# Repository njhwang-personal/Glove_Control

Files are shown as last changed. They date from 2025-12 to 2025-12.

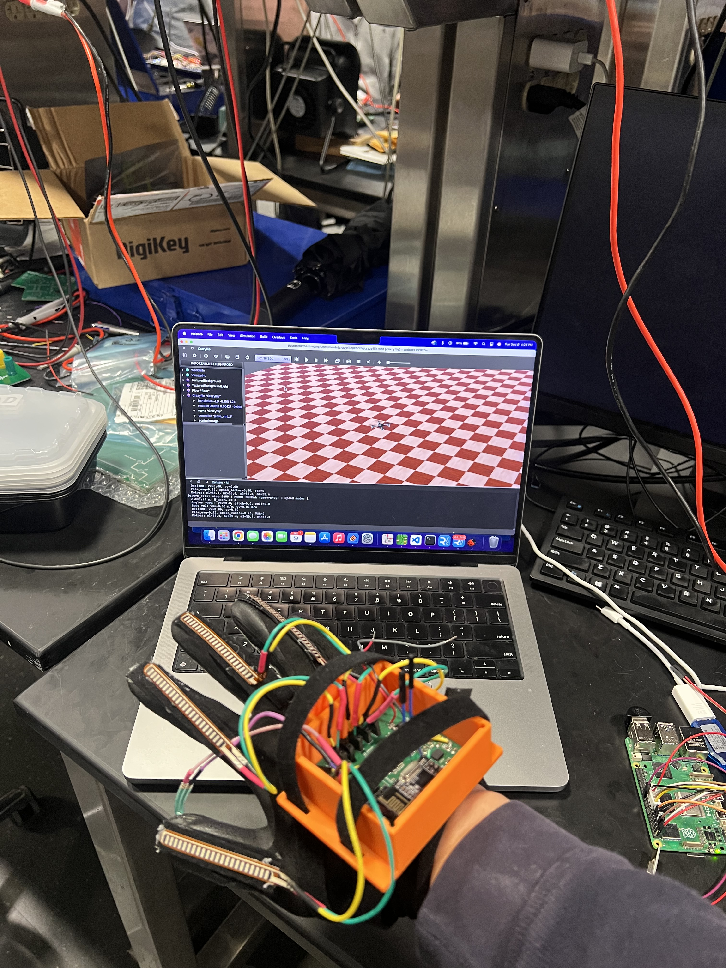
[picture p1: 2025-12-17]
IMG_4266.jpeg

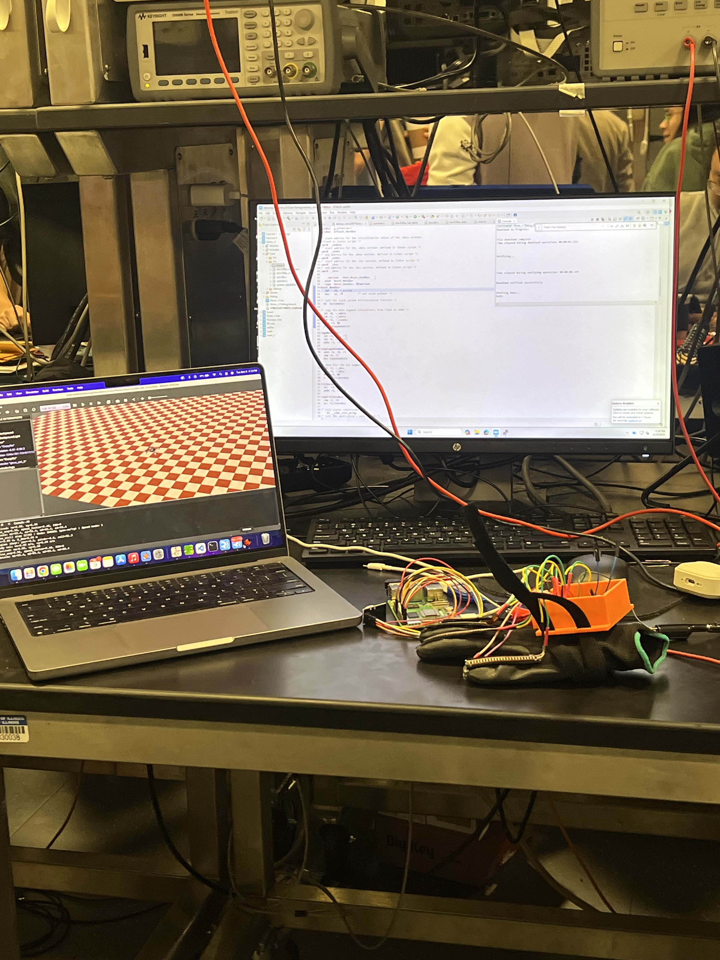
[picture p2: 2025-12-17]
IMG_4262.jpeg

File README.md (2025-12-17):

# Glove-Controlled Drone

## Overview
This project implements a wearable glove controller for drone control using a custom PCB, wireless communication, and a simulated drone environment.

## Repository Contents
- `glove_ctrl.py` – Webots controller code
- `glove_main.c` – STM32 firmware (STM32CubeIDE)
- `pi_receiver_final.c` – Raspberry Pi RF receiver and UDP bridge
- `Glove_32pin.kicad*` – KiCad schematic and PCB layout files for the glove controller

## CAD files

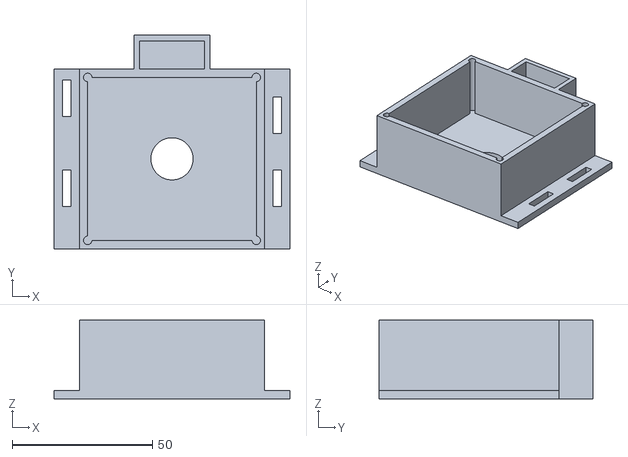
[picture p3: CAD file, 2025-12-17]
Gloves_case_final.stl
84.0 x 76.0 x 28.0

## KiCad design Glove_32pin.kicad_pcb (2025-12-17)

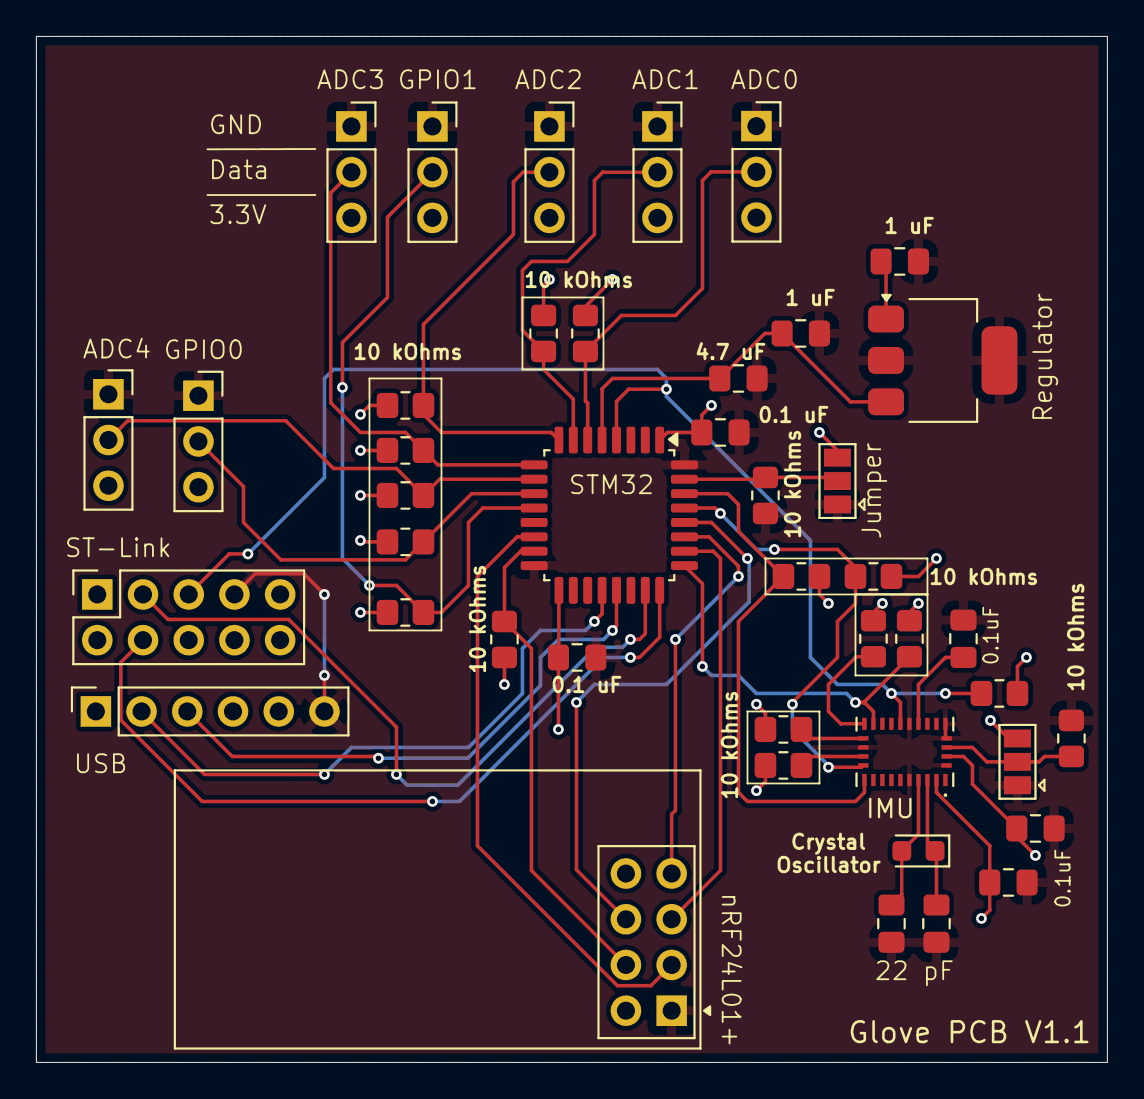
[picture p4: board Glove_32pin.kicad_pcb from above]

Board: 2 copper layers, 59.5 x 57.0 mm, 43 parts (0 on the bottom side), 32 nets.

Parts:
C1, C2: 1 uF; C_0805_2012Metric_Pad1.18x1.45mm_HandSolder
C3, C4, C6, C7, C10: 0.1 uF; C_0805_2012Metric_Pad1.18x1.45mm_HandSolder
C5: 4.7 uF; C_0805_2012Metric_Pad1.18x1.45mm_HandSolder
C8, C9: 22 pF; C_0805_2012Metric_Pad1.18x1.45mm_HandSolder
J3, J4, J5, J6, J7, J8, J9: Conn_01x03_Pin; PinSocket_1x03_P2.54mm_Vertical
J10: ST-Link; PinSocket_2x05_P2.54mm_Vertical
J12: Conn_01x06_Socket; PinSocket_1x06_P2.54mm_Vertical
JP1, JP4: SolderJumper_3_Open; SolderJumper-3_P1.3mm_Open_Pad1.0x1.5mm
R1, R13: 10KOhms; R_0805_2012Metric_Pad1.20x1.40mm_HandSolder
R2, R3, R4, R12: 4.7 kOhms; R_0805_2012Metric_Pad1.20x1.40mm_HandSolder
R5, R6, R7, R8, R9, R10, R11: 22 kOhms; R_0805_2012Metric_Pad1.20x1.40mm_HandSolder
R14, R15, R16, R19: 10K; R_0805_2012Metric_Pad1.20x1.40mm_HandSolder
U1: STM32L031K6Tx; LQFP-32_7x7mm_P0.8mm
U2: TC1262-33; SOT-223-3_TabPin2
U3: BNO085; IC_BNO085
U5: NRF24L01_Breakout; nRF24L01_Breakout
X1: 32.768; Crystal_SMD_2012-2Pin_2.0x1.2mm_HandSoldering

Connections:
+3.3V: C3.2, C4.1, C7.1, C10.1, J3.3, J4.3, J5.3, J6.3, J7.3, J8.3, J9.3, J10.1, J10.6, JP1.3 (B), JP4.3 (B), R2.2, R3.2, R4.2, R5.1, R6.1, R7.1, R8.1, R9.1, R10.1, R11.1, R12.2, R14.2, R15.2, R16.1, R19.1, U1.1 (VDD), U1.17 (VDD), U3.3 (VDD), U3.28 (VDDIO), U5.2 (VCC)
+5V: C2.1, U2.1 (VI)
/ADC0: J3.2, R5.2, U1.6 (PA0)
/ADC1: J4.2, R6.2, U1.7 (PA1)
/ADC2: J5.2, R7.2, U1.8 (PA2)
/ADC3: J6.2, R8.2, U1.9 (PA3)
/ADC4: J7.2, R9.2, U1.10 (PA4)
/GPIO_0: J8.2, R10.2, U1.11 (PA5)
/GPIO_1: J9.2, R11.2, U1.12 (PA6)
/I2C_SCL: R3.1, U1.29 (PB6), U3.19 (H_SCL/SCK/RX)
/I2C_SDA: R2.1, U1.30 (PB7), U3.20 (H_SDA/H_MISO/TX)
/INT: R12.1, U1.25 (PA15), U3.14 (~H_INT)
/LPUART_Rx: J12.3, U1.21 (PA11)
/LPUART_Tx: J12.2, U1.20 (PA10)
/NRST: J10.5, R19.2, U1.4 (NRST), U3.11 (~RST)
/SPI_CE: U1.14 (PB0), U5.3 (CE)
/SPI_CSN: R4.1, U1.15 (PB1), U5.4 (~CSN)
/SPI_MISO: U1.27 (PB4), U5.7 (MISO)
/SPI_MOSI: U1.28 (PB5), U5.6 (MOSI)
/SPI_SCK: U1.26 (PB3), U5.5 (SCK)
/SWCLK: J10.4, U1.24 (PA14)
/SWDIO: J10.3, U1.23 (PA13)
/XIN: C8.1, U3.27 (XIN32), X1.1
/XOUT: C9.1, U3.26 (XOUT32/CLKSEL1), X1.2
GND: C1.2, C2.2, C3.1, C4.2, C5.2, C6.2, C7.2, C8.2, C9.2, C10.2, J3.1, J4.1, J5.1, J6.1, J7.1, J8.1, J9.1, J10.7, J12.6, JP1.1 (A), JP4.1 (A), R1.2, R13.2, U1.16 (VSS), U1.32 (VSS), U2.2 (GND), U3.2 (GND), U3.5 (PS1), U3.6 (PS0/WAKE), U3.10 (CLKSEL0), U3.17 (SA0/H_MOSI), U3.25 (GNDIO), U5.1 (GND)
unnamed: JP1.2 (C), R1.1, U1.31 (BOOT0)
unnamed: JP4.2 (C), R13.1, U3.4 (~BOOT)
unnamed: C1.1, C5.1, U1.5 (VDDA), U2.3 (VO)
unnamed: C6.1, U3.9 (CAP)
unnamed: R14.1, U3.15 (ENV_SCL)
unnamed: R15.1, U3.16 (ENV_SDA)
unnamed: R16.2, U3.18 (~H_CS)

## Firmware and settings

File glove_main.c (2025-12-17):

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
/* Includes ------------------------------------------------------------------*/
#include "main.h"

#include <stdio.h>
#include <stdlib.h>
#include <string.h>
#include <math.h>
#include <stdint.h>
#include <stdbool.h>

/* USER CODE END Includes */


/* USER CODE BEGIN PTD */

////// Define for Bno085 //////
#define RAD_TO_DEG (57.2957795131f)
#define SCALE_Q14 (1.0f/16384.0f)
#define BNO_I2C_ADDRESS (0x4A << 1)
#define BNO_I2C_HANDLE &hi2c1
#define BNO_MSG_LENGTH 21
#define BNO_READ_PERIOD 20 //ms


ADC_HandleTypeDef hadc;
I2C_HandleTypeDef hi2c1;
UART_HandleTypeDef huart4;
SPI_HandleTypeDef hspi1;


uint8_t START_BNO_STABILIZED_ROTATION_VECTOR_100_HZ[/* BNO_MSG_LENGTH */] =
{ 0x15, 0x00, 0x02, 0x00, 0xFD, 0x28, 0x00, 0x00, 0x00, 0x10, 0x27, 0x00, 0x00,
	0x00, 0x00, 0x00, 0x00, 0x00, 0x00, 0x00, 0x00 };

uint8_t FishedOutMessage[BNO_MSG_LENGTH];
uint8_t BnoRxBuff[BNO_MSG_LENGTH];
static int16_t Data1, Data2, Data3, Data4;



typedef struct __attribute__((packed)){
    uint8_t  magic;      //0xAA
    uint8_t  version;
    uint16_t seq;

    int16_t  yaw;
    int16_t  pitch;
    int16_t  roll;

    uint8_t  flex[5];
    uint8_t  contacts;

    uint16_t batt_mv;    //battery (unused)

    uint8_t  reserved[12];  //future use

    uint16_t checksum;   //16-bit sum of first 30 bytes
} GlovePacket;

static uint16_t g_seq = 0; //global sequence counter





float Y_callibrate, P_callibrate, R_callibrate;
int iteration_enregistrement = 0;
static int calibration = 15;
uint32_t BnoSoftTimer;

#define DELTA_1I_Y (2)
#define DELTA_2I_Y (10)
#define DELTA_1D_Y (2)
#define DELTA_2D_Y (10)

#define DELTA_1I_P (2)
#define DELTA_2I_P (10)
#define DELTA_1D_P (2)
#define DELTA_2D_P (10)

#define DELTA_1I_R (2)
#define DELTA_2I_R (10)
#define DELTA_1D_R (2)
#define DELTA_2D_R (10)


int number_mesures = 5;


////// Define for Flex and FSR //////

#define FLEX_SENSOR_COUNT 4


static const uint32_t flex_channel_masks[FLEX_SENSOR_COUNT] = {
    ADC_CHANNEL_1,   //Flex 0
    ADC_CHANNEL_2,   //Flex 1
    ADC_CHANNEL_3,   //Flex 2
    ADC_CHANNEL_4    //Flex 3
};


#define FSR_GPIO_PORT GPIOA
#define FSR_GPIO_PIN GPIO_PIN_5

#define FSR_SAMPLE_PERIOD_MS 5 //~200 Hz
#define FLEX_SAMPLE_PERIOD_MS 10 //~100 Hz


//FSR thresholds
#define FSR_DELTA_PRESSED 2000
#define FSR_DELTA_RELEASED 500

//Flex thresholds
#define DELTA_FLEX_LOW 50
#define DELTA_FLEX_MID_1 75
#define DELTA_FLEX_MID_2 100
#define DELTA_FLEX_HIGH 130


static uint16_t flex_cal_adc[FLEX_SENSOR_COUNT];
static uint8_t  flex_last_state[FLEX_SENSOR_COUNT];
static uint32_t flex_last_ts_ms = 0;




///////////////////////////////  RADIO  ////////////////////////////////
#define NRF_CE_PORT   GPIOB
#define NRF_CE_PIN    GPIO_PIN_0
#define NRF_CSN_PORT  GPIOB
#define NRF_CSN_PIN   GPIO_PIN_1


#define NRF_CMD_R_REGISTER     0x00
#define NRF_CMD_W_REGISTER     0x20
#define NRF_CMD_R_RX_PAYLOAD   0x61
#define NRF_CMD_W_TX_PAYLOAD   0xA0
#define NRF_CMD_FLUSH_TX       0xE1
#define NRF_CMD_FLUSH_RX       0xE2
#define NRF_CMD_NOP            0xFF


#define NRF_REG_CONFIG         0x00
#define NRF_REG_EN_AA          0x01
#define NRF_REG_EN_RXADDR      0x02
#define NRF_REG_SETUP_AW       0x03
#define NRF_REG_SETUP_RETR     0x04
#define NRF_REG_RF_CH          0x05
#define NRF_REG_RF_SETUP       0x06
#define NRF_REG_STATUS         0x07
#define NRF_REG_RX_ADDR_P0     0x0A
#define NRF_REG_TX_ADDR        0x10
#define NRF_REG_RX_PW_P0       0x11
#define NRF_REG_FIFO_STATUS    0x17
#define NRF_REG_DYNPD          0x1C



#define NRF_MASK_RX_DR         (1 << 6)
#define NRF_MASK_TX_DS         (1 << 5)
#define NRF_MASK_MAX_RT        (1 << 4)
#define NRF_EN_CRC             (1 << 3)
#define NRF_CRCO               (1 << 2)
#define NRF_PWR_UP             (1 << 1)
#define NRF_PRIM_RX            (1 << 0)


#define NRF_RX_DR              (1 << 6)
#define NRF_TX_DS              (1 << 5)
#define NRF_MAX_RT             (1 << 4)


static inline void nrf_csn_low(void){ HAL_GPIO_WritePin(NRF_CSN_PORT, NRF_CSN_PIN, GPIO_PIN_RESET); }
static inline void nrf_csn_high(void){ HAL_GPIO_WritePin(NRF_CSN_PORT, NRF_CSN_PIN, GPIO_PIN_SET); }
static inline void nrf_ce_low(void){ HAL_GPIO_WritePin(NRF_CE_PORT, NRF_CE_PIN, GPIO_PIN_RESET); }
static inline void nrf_ce_high(void){ HAL_GPIO_WritePin(NRF_CE_PORT, NRF_CE_PIN, GPIO_PIN_SET); }

int Bno_read(float *yaw, float *pitch, float *roll);
void Bno_init(void);

void Flex_callibration(void);
void Flex_Task(uint8_t out_states[FLEX_SENSOR_COUNT]);

//void FSR_callibration(void);
uint8_t FSR_Task(void);



static uint8_t nrf_spi_xfer(uint8_t byte)
{
    uint8_t rx;
    HAL_SPI_TransmitReceive(&hspi1, &byte, &rx, 1, HAL_MAX_DELAY);
    return rx;
}



static uint8_t nrf_read_reg(uint8_t reg)
{
    uint8_t val;
    nrf_csn_low();
    nrf_spi_xfer(NRF_CMD_R_REGISTER | (reg & 0x1F));
    val = nrf_spi_xfer(0xFF);
    nrf_csn_high();
    return val;
}


static void nrf_write_reg(uint8_t reg, uint8_t val)
{
    nrf_csn_low();
    nrf_spi_xfer(NRF_CMD_W_REGISTER | (reg & 0x1F));
    nrf_spi_xfer(val);
    nrf_csn_high();
}



static void nrf_write_buf(uint8_t reg, const uint8_t *buf, uint8_t len)
{
    nrf_csn_low();
    nrf_spi_xfer(NRF_CMD_W_REGISTER | (reg & 0x1F));
    for (uint8_t i = 0; i < len; i++)
        nrf_spi_xfer(buf[i]);
    nrf_csn_high();
}


static void nrf_flush_tx(void)
{
    nrf_csn_low();
    nrf_spi_xfer(NRF_CMD_FLUSH_TX);
    nrf_csn_high();
}



static void nrf_flush_rx(void)
{
    nrf_csn_low();
    nrf_spi_xfer(NRF_CMD_FLUSH_RX);
    nrf_csn_high();
}



static void nrf_clear_irq(void)
{
    nrf_write_reg(NRF_REG_STATUS, NRF_RX_DR | NRF_TX_DS | NRF_MAX_RT);
}




void nrf_init_tx(void)
{
    uint8_t addr[5] = {0xE7, 0xE7, 0xE7, 0xE7, 0xE7};

    nrf_ce_low();
    nrf_csn_high();
    HAL_Delay(5);

    nrf_write_reg(NRF_REG_EN_AA, 0x00);

    nrf_write_reg(NRF_REG_EN_RXADDR, 0x01);

    nrf_write_reg(NRF_REG_SETUP_AW, 0x03);

    nrf_write_reg(NRF_REG_SETUP_RETR, 0x00);

    nrf_write_reg(NRF_REG_RF_CH, 76);

    nrf_write_reg(NRF_REG_RF_SETUP, 0x06);

    nrf_write_buf(NRF_REG_TX_ADDR, addr, 5);
    nrf_write_buf(NRF_REG_RX_ADDR_P0, addr, 5);

    nrf_write_reg(NRF_REG_RX_PW_P0, 32);

    nrf_write_reg(NRF_REG_DYNPD, 0x00);

    nrf_flush_tx();
    nrf_flush_rx();
    nrf_clear_irq();


    uint8_t config = NRF_EN_CRC | NRF_PWR_UP; //0x0A
    nrf_write_reg(NRF_REG_CONFIG, config);

    HAL_Delay(5);

}



bool nrf_send_payload(const uint8_t *data, uint8_t len)

{
    if (len == 0 || len > 32)
        return false;

    uint8_t cfg = nrf_read_reg(NRF_REG_CONFIG);
    cfg &= ~NRF_PRIM_RX;
    cfg |= NRF_PWR_UP;
    nrf_write_reg(NRF_REG_CONFIG, cfg);
    HAL_Delay(5);

    nrf_flush_tx();
    nrf_clear_irq();

    //Write payload
    nrf_csn_low();
    nrf_spi_xfer(NRF_CMD_W_TX_PAYLOAD);
    for (uint8_t i = 0; i < len; i++)
        nrf_spi_xfer(data[i]);
    nrf_csn_high();

    nrf_ce_high();

    for (volatile int i = 0; i < 1000; i++) __NOP();
    nrf_ce_low();

    uint32_t start = HAL_GetTick();
    while (1)
    {
        uint8_t status = nrf_read_reg(NRF_REG_STATUS);
        if (status & NRF_TX_DS)
        {
            nrf_clear_irq();
            return true;
        }
        if (status & NRF_MAX_RT)
        {
            nrf_clear_irq();
            nrf_flush_tx();
            return false;    //failed
        }
        if (HAL_GetTick() - start > 100)
        {
            return false;
        }
    }
}
/////////////////////////////////  END RADIO SECTION  /////////////////////////////////


/* USER CODE END PTD */




static int build_glove_packet_from_sensors(GlovePacket *pkt)
{

    static float last_yaw   = 0.0f;
    static float last_pitch = 0.0f;
    static float last_roll  = 0.0f;

    float yaw, pitch, roll;

    if (Bno_read(&yaw, &pitch, &roll)){
        last_yaw   = yaw;
        last_pitch = pitch;
        last_roll  = roll;
    }

    uint8_t fsr  = FSR_Task();
    uint8_t flex_states[FLEX_SENSOR_COUNT];

    Flex_Task(flex_states);
    memset(pkt, 0, sizeof(*pkt));

    pkt->magic   = 0xAA;
    pkt->version = 1;
    pkt->seq     = g_seq++;

    pkt->yaw   = (int16_t)(last_yaw   * 100.0f);
    pkt->pitch = (int16_t)(last_pitch * 100.0f);
    pkt->roll  = (int16_t)(last_roll  * 100.0f);


    pkt->flex[0] = flex_states[0];
    pkt->flex[1] = flex_states[1];
    pkt->flex[2] = flex_states[2];
    pkt->flex[3] = flex_states[3];
    pkt->flex[4] = 0;


    pkt->contacts = 0;
    if (fsr){
        pkt->contacts |= (1 << 0);
    }

    pkt->batt_mv = 0;

    const uint8_t *bytes = (const uint8_t *)pkt;
    uint16_t sum = 0;
    for(int i = 0; i < 30; i++){
        sum += bytes[i];
    }
    pkt->checksum = sum;

    return 1;
}









/* USER CODE BEGIN PV */

int __io_putchar(int ch){
	uint8_t c = (uint8_t)ch ;
	if (c == '\n') {
	uint8_t cr = '\r';
	HAL_UART_Transmit(&huart4, &cr, 1, HAL_MAX_DELAY);
	}
	HAL_UART_Transmit(&huart4, &c, 1, HAL_MAX_DELAY);
	return ch;
}



static void ADC_SelectSingleChannel(ADC_HandleTypeDef *phadc, uint32_t ch_mask)
{

    HAL_ADC_Stop(phadc);

    phadc->Instance->CHSELR = 0;
    phadc->Instance->CHSELR = ch_mask;
}



float my_fmodf(float x, float y){
    if (y == 0.0f) {

        return 0.0f / 0.0f;
    }

    int quotient = (int)(x / y);
    float result = x - (float)quotient * y;


    if ((result > 0.0f && y < 0.0f) || (result < 0.0f && y > 0.0f)){
        result += y;
    }

    return result;
}

static float mod360(float x){
    float r = my_fmodf(x, 360.0);
    return (r < 0.0) ? r + 360.0 : r;
}


static float angle_diff_signed(float a_before, float a_after){
    return mod360((a_after - a_before) + 540.0) - 180.0;
}



/////////////////// Functions for BNO ////////////////////////
void bno_callibration(float y_c, float p_c, float r_c){
	Y_callibrate = y_c;
	P_callibrate = p_c ;
	R_callibrate = r_c;
	printf("c\r\n");
	//printf("Yc %ld\r\n", (long)lroundf(y_c));
	//printf("Pc %ld\r\n", (long)lroundf(p_c));
	//printf("Rc %ld\r\n", (long)lroundf(r_c));
}


int Bno_read(float *yaw, float *pitch, float *roll)
{
    float Qi, Qj, Qk, Qr;

    if (HAL_GetTick() - BnoSoftTimer < BNO_READ_PERIOD){
        return 0;
    }
    BnoSoftTimer = HAL_GetTick();

    HAL_StatusTypeDef st = HAL_I2C_Master_Receive(
        BNO_I2C_HANDLE,
        BNO_I2C_ADDRESS,
        BnoRxBuff,
        BNO_MSG_LENGTH,
        10
    );

    if (st != HAL_OK) {
         printf("I2C RX err=0x%lX\r\n", HAL_I2C_GetError(BNO_I2C_HANDLE));
        return 0;
    }

     printf("BNO RAW: ");
     for (int i = 0; i < BNO_MSG_LENGTH; i++){
         printf("%02X ", BnoRxBuff[i]);
     }
     printf("\r\n");

    int rep_idx = -1;
    for (int i = 0; i < BNO_MSG_LENGTH; i++){
        if (BnoRxBuff[i] == 0x28) {
            rep_idx = i;
            break;
        }
    }

    if (rep_idx < 0){
        return 0;
    }

    if (rep_idx + 11 >= BNO_MSG_LENGTH){
        return 0;
    }

    int16_t d1 = (int16_t)(((uint16_t)BnoRxBuff[rep_idx + 5] << 8) | BnoRxBuff[rep_idx + 4]);
    int16_t d2 = (int16_t)(((uint16_t)BnoRxBuff[rep_idx + 7] << 8) | BnoRxBuff[rep_idx + 6]);
    int16_t d3 = (int16_t)(((uint16_t)BnoRxBuff[rep_idx + 9] << 8) | BnoRxBuff[rep_idx + 8]);
    int16_t d4 = (int16_t)(((uint16_t)BnoRxBuff[rep_idx + 11] << 8) | BnoRxBuff[rep_idx + 10]);

    Qi = d2 * SCALE_Q14;
    Qj = d3 * SCALE_Q14;
    Qk = d4 * SCALE_Q14;
    Qr = d1 * SCALE_Q14;

    float qi2 = Qi * Qi;
    float qj2 = Qj * Qj;
    float qk2 = Qk * Qk;
    float qr2 = Qr * Qr;
    float denom = qi2 + qj2 + qk2 + qr2;
    if (denom == 0.0f){
        return 0;
    }

    *yaw   = atan2f(2.0f * (Qi * Qj + Qk * Qr),
                    (qi2 - qj2 - qk2 + qr2))*RAD_TO_DEG;
    *pitch = asinf(-2.0f * (Qi * Qk - Qj * Qr) / denom) * RAD_TO_DEG;
    *roll  = atan2f(2.0f * (Qj * Qk + Qi * Qr),
                    (-qi2 - qj2 + qk2 + qr2))*RAD_TO_DEG;

    iteration_enregistrement++;
    if (iteration_enregistrement == calibration){
        bno_callibration(*yaw, *pitch, *roll);
    }

    return 1;
}

void Bno_init(void){
	HAL_I2C_Master_Transmit(BNO_I2C_HANDLE, BNO_I2C_ADDRESS,
	START_BNO_STABILIZED_ROTATION_VECTOR_100_HZ,
	sizeof(START_BNO_STABILIZED_ROTATION_VECTOR_100_HZ), 10);
	HAL_Delay(100);
	BnoSoftTimer = HAL_GetTick();
}



/////////////////////////////// Function for Flex and FSR ////////////////////////////////////////

static uint16_t ADC_ReadChannel(uint32_t channel_mask)
{
    ADC_SelectSingleChannel(&hadc, channel_mask);

    HAL_ADC_Start(&hadc);
    HAL_ADC_PollForConversion(&hadc, HAL_MAX_DELAY);
    (void)HAL_ADC_GetValue(&hadc);
    HAL_ADC_Stop(&hadc);
    HAL_ADC_Start(&hadc);
    HAL_ADC_PollForConversion(&hadc, HAL_MAX_DELAY);
    (void)HAL_ADC_GetValue(&hadc);
    HAL_ADC_Stop(&hadc);

    HAL_ADC_Start(&hadc);
    HAL_ADC_PollForConversion(&hadc, HAL_MAX_DELAY);
    uint16_t val = (uint16_t)HAL_ADC_GetValue(&hadc);
    HAL_ADC_Stop(&hadc);

    return val;

}



static uint16_t ADC_ReadAvg(uint32_t channel_mask, uint8_t n)
{
    uint32_t acc = 0;
    for (uint8_t i = 0; i < n; i++) {
        acc += ADC_ReadChannel(channel_mask);
    }
    return (uint16_t)(acc / n);
}

void Flex_callibration(void){
	const uint8_t samples = 8;

    for (int i = 0; i < FLEX_SENSOR_COUNT; i++) {
        uint16_t adc = ADC_ReadAvg(flex_channel_masks[i], samples);
        flex_cal_adc[i]   = adc;
        flex_last_state[i] = 0;
    	printf("Flex %d cal_adc = %u \r\n", i, adc);
    }

}


void Flex_Task(uint8_t out_states[FLEX_SENSOR_COUNT])
{
    const uint8_t samples = 8;
    uint32_t now = HAL_GetTick();

    if ((now - flex_last_ts_ms) < FLEX_SAMPLE_PERIOD_MS){

        for(int i = 0; i < FLEX_SENSOR_COUNT; i++){
            out_states[i] = flex_last_state[i];
        }
        return;
    }
    flex_last_ts_ms = now;

    for(int i = 0; i < FLEX_SENSOR_COUNT; i++){
        uint16_t adc = ADC_ReadAvg(flex_channel_masks[i], samples);
        uint16_t cal = flex_cal_adc[i];
        uint16_t diff = (adc > cal) ? (adc - cal) : (cal - adc);

        uint8_t state;
        if (diff >= DELTA_FLEX_HIGH){
            state = 4;
        } 
        else if (diff >= DELTA_FLEX_MID_2){
            state = 3;
        } 
        else if (diff >= DELTA_FLEX_MID_1){
            state = 2;
        } 
        else if (diff >= DELTA_FLEX_LOW){
            state = 1;
        } 
        else{
            state = 0;
        }

        if (state != flex_last_state[i]) {
            flex_last_state[i] = state;
            // printf("Flex %d state = %u (ADC=%u, cal=%u)\r\n", i, state, adc, cal);
        }

        out_states[i] = state;
        //printf("Flex%d: adc = %u cal=%u diff=%u state=%u\r\n", i, adc, cal, diff, state);
    }
}


uint8_t FSR_Task(void)	//changed from adc to gpio
{
// static uint32_t last_ts_ms = 0;
// static uint8_t is_pressed = 0;
// const uint8_t samples = 8;
//
// uint32_t now = HAL_GetTick();
// if ((now - last_ts_ms) < FSR_SAMPLE_PERIOD_MS){
//    return is_pressed;
// }
//
// last_ts_ms = now;
//
// uint16_t adc = ADC_ReadAvg(FSR_ADC_CHANNEL, samples);
//
// //printf("adc fsr %u\r\n", adc);
//
// uint16_t diff = (adc > fsr_cal_adc) ? (adc - fsr_cal_adc) : (fsr_cal_adc - adc);
// if (!is_pressed) {
//    if (diff >= FSR_DELTA_PRESSED) {
//    is_pressed = 1;
//    //printf("Pressed\r\n");
//    }
// } else {
//    if (diff <= FSR_DELTA_RELEASED) {
//        is_pressed = 0;
//        //printf("Released\r\n");
//    }
// }
//return is_pressed;

	GPIO_PinState s = HAL_GPIO_ReadPin(FSR_GPIO_PORT, FSR_GPIO_PIN);
	return (s == GPIO_PIN_RESET) ? 1 : 0;
}

/* USER CODE END PV */

void SystemClock_Config(void);
static void MX_GPIO_Init(void);
static void MX_I2C1_Init(void);
static void MX_USART4_UART_Init(void);
static void MX_ADC_Init(void);
static void MX_SPI1_Init(void);
/**
 * @brief The application entry point.
 * @retval int
 */
int main(void)
{
 /* MCU Configuration--------------------------------------------------------*/

 /* Reset of all peripherals, Initializes the Flash interface and the Systick. */

    HAL_Init();

    /* Configure the system clock */

    SystemClock_Config();

    /* Initialize all configured peripherals */
    MX_GPIO_Init();
    MX_I2C1_Init();
    MX_USART4_UART_Init();
    MX_ADC_Init();
    MX_SPI1_Init();
    nrf_init_tx();

    /* USER CODE BEGIN 2 */
    Bno_init();

 // bno_callibration(&Y_callibrate, &P_callibrate, &R_callibrate);
	printf("D\n");
	uint8_t fsr = 0;
	Flex_callibration();
	//FSR_callibration();

    GlovePacket pkt;
 /* USER CODE END 2 */

 /* USER CODE BEGIN WHILE */
    printf("entering loop \n");
    /* USER CODE BEGIN 2 */
    printf("Scanning I2C bus...\r\n");
    HAL_StatusTypeDef result;
    for(int i = 1; i < 128; i++) {

    	result = HAL_I2C_IsDeviceReady(&hi2c1, (uint16_t)(i << 1), 2, 2);
    	if(result == HAL_OK){
    		printf("Device found at 0x%02X\r\n", i);
    		HAL_Delay(1);
    	}
    }

    /* USER CODE END 2 */
    //Bno_init();
 while (1)

 {
 /* USER CODE END WHILE */


 /* USER CODE BEGIN 3 */

    // New: build and send RF packet when IMU has fresh data
	 printf("looking for packet \n");
        if(build_glove_packet_from_sensors(&pkt)){
            int ok = nrf_send_payload((uint8_t *)&pkt, sizeof(pkt));

            char dbg[64];
            snprintf(dbg, sizeof(dbg), "TX ok=%d seq=%u yaw=%d pitch=%d roll=%d flex= [%u, %u, %u, %u], fsr=%u\r\n",ok, pkt.seq, (int)pkt.yaw, (int)pkt.pitch, (int)pkt.roll, pkt.flex[0],
            		pkt.flex[1], pkt.flex[2], pkt.flex[3], (pkt.contacts & 0x01) ? 1 : 0);
            HAL_UART_Transmit(&huart4, (uint8_t*)dbg, strlen(dbg), HAL_MAX_DELAY);
        }
      HAL_Delay(20);
	}
 /* USER CODE END 3 */
}

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


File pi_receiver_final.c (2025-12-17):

#define _GNU_SOURCE

#include <stdio.h>
#include <stdint.h>
#include <string.h>
#include <stdlib.h>
#include <unistd.h>
#include <fcntl.h>
#include <sys/ioctl.h>
#include <linux/spi/spidev.h>
#include <gpiod.h>

#include <arpa/inet.h>
#include <sys/socket.h>
#include <netinet/in.h>

//nRF24L01+ commands & registers 
#define NRF_CMD_R_REGISTER     0x00
#define NRF_CMD_W_REGISTER     0x20
#define NRF_CMD_R_RX_PAYLOAD   0x61
#define NRF_CMD_W_TX_PAYLOAD   0xA0
#define NRF_CMD_FLUSH_TX       0xE1
#define NRF_CMD_FLUSH_RX       0xE2
#define NRF_CMD_NOP            0xFF

#define NRF_REG_CONFIG         0x00
#define NRF_REG_EN_AA          0x01
#define NRF_REG_EN_RXADDR      0x02
#define NRF_REG_SETUP_AW       0x03
#define NRF_REG_SETUP_RETR     0x04
#define NRF_REG_RF_CH          0x05
#define NRF_REG_RF_SETUP       0x06
#define NRF_REG_STATUS         0x07
#define NRF_REG_RX_ADDR_P0     0x0A
#define NRF_REG_TX_ADDR        0x10
#define NRF_REG_RX_PW_P0       0x11
#define NRF_REG_FIFO_STATUS    0x17
#define NRF_REG_DYNPD          0x1C

//CONFIG bits
#define NRF_MASK_RX_DR         (1 << 6)
#define NRF_MASK_TX_DS         (1 << 5)
#define NRF_MASK_MAX_RT        (1 << 4)
#define NRF_EN_CRC             (1 << 3)
#define NRF_CRCO               (1 << 2)
#define NRF_PWR_UP             (1 << 1)
#define NRF_PRIM_RX            (1 << 0)

//STATUS bits
#define NRF_RX_DR              (1 << 6)
#define NRF_TX_DS              (1 << 5)
#define NRF_MAX_RT             (1 << 4)

//RF params
#define RF_CHANNEL             76 
#define RF_SETUP_VAL           0x06    // 1 Mbps, 0 dBm
static const uint8_t RF_ADDR[5] = {0xE7, 0xE7, 0xE7, 0xE7, 0xE7};

//UDP 
#define DEFAULT_DEST_IP   "<IP address>"  // IP here
#define DEFAULT_DEST_PORT 5005

//Packet Layout

typedef struct __attribute__((packed)){
    uint8_t  magic;      //0xAA
    uint8_t  version;
    uint16_t seq;

    int16_t  yaw;
    int16_t  pitch;
    int16_t  roll;

    uint8_t  flex[5];
    uint8_t  contacts;

    uint16_t batt_mv;    //battery (unused)

    uint8_t  reserved[12];  //future use

    uint16_t checksum;   //16-bit sum of first 30 bytes
} GlovePacket;

//CE Pin
#define CE_GPIO_NUM 17


static struct gpiod_chip *ce_chip = NULL;
static struct gpiod_line *ce_line = NULL;

static int gpio_init_ce(void)
{
    ce_chip = gpiod_chip_open_by_name("gpiochip0");
    if (!ce_chip){
        perror("gpiod_chip_open_by_name");
        return -1;
    }

    ce_line = gpiod_chip_get_line(ce_chip, CE_GPIO_NUM);
    if (!ce_line){
        perror("gpiod_chip_get_line");
        return -1;
    }

    if (gpiod_line_request_output(ce_line, "nrf24-ce", 0) < 0){
        perror("gpiod_line_request_output");
        return -1;
    }

    return 0;
}

static void gpio_set_ce(int level)
{
    if (!ce_line){
        return;
    }
    if (gpiod_line_set_value(ce_line, level) < 0){
        perror("gpiod_line_set_value");
    }
}

//SPI
static int spi_fd = -1;

static int spi_init(const char *device)
{
    uint8_t mode = 0;
    uint8_t bits = 8;
    uint32_t speed = 1000000; //1 MHz

    spi_fd = open(device, O_RDWR);
    if (spi_fd < 0){
        perror("open(spidev)");
        return -1;
    }

    if (ioctl(spi_fd, SPI_IOC_WR_MODE, &mode) < 0){
        perror("SPI_IOC_WR_MODE");
        return -1;
    }
    if (ioctl(spi_fd, SPI_IOC_WR_BITS_PER_WORD, &bits) < 0){
        perror("SPI_IOC_WR_BITS_PER_WORD");
        return -1;
    }
    if (ioctl(spi_fd, SPI_IOC_WR_MAX_SPEED_HZ, &speed) < 0){
        perror("SPI_IOC_WR_MAX_SPEED_HZ");
        return -1;
    }

    return 0;
}

static uint8_t spi_xfer_byte(uint8_t data)
{
    uint8_t rx = 0;
    struct spi_ioc_transfer tr = {
        .tx_buf = (unsigned long)&data,
        .rx_buf = (unsigned long)&rx,
        .len = 1,
        .speed_hz = 1000000,
        .delay_usecs = 0,
        .bits_per_word = 8,
    };

    if (ioctl(spi_fd, SPI_IOC_MESSAGE(1), &tr) < 0){
        perror("SPI_IOC_MESSAGE");
        return 0xFF;
    }
    return rx;
}

//nRF24L01+
static uint8_t nrf_read_reg(uint8_t reg)
{
    uint8_t tx[2] = { NRF_CMD_R_REGISTER | (reg & 0x1F), 0xFF };
    uint8_t rx[2] = { 0 };

    struct spi_ioc_transfer tr = {
        .tx_buf = (unsigned long)tx,
        .rx_buf = (unsigned long)rx,
        .len = 2,
        .speed_hz = 1000000,
        .delay_usecs = 0,
        .bits_per_word = 8,
    };

    if (ioctl(spi_fd, SPI_IOC_MESSAGE(1), &tr) < 0){
        perror("SPI_IOC_MESSAGE");
        return 0xFF;
    }

    return rx[1];
}

static void nrf_write_reg(uint8_t reg, uint8_t val)
{
    uint8_t tx[2] = { NRF_CMD_W_REGISTER | (reg & 0x1F), val };
    uint8_t rx[2] = { 0 };

    struct spi_ioc_transfer tr = {
        .tx_buf = (unsigned long)tx,
        .rx_buf = (unsigned long)rx,
        .len = 2,
        .speed_hz = 1000000,
        .delay_usecs = 0,
        .bits_per_word = 8,
    };

    if (ioctl(spi_fd, SPI_IOC_MESSAGE(1), &tr) < 0){
        perror("SPI_IOC_MESSAGE");
    }
}

static void nrf_write_buf(uint8_t reg, const uint8_t *buf, uint8_t len)
{
    uint8_t tx[1 + 32] = {0};
    uint8_t rx[1 + 32] = {0};

    if (len > 32) len = 32;

    tx[0] = NRF_CMD_W_REGISTER | (reg & 0x1F);
    memcpy(&tx[1], buf, len);

    struct spi_ioc_transfer tr = {
        .tx_buf = (unsigned long)tx,
        .rx_buf = (unsigned long)rx,
        .len    = len + 1,
        .speed_hz = 1000000,
        .delay_usecs = 0,
        .bits_per_word = 8,
    };

    if (ioctl(spi_fd, SPI_IOC_MESSAGE(1), &tr) < 0){
        perror("SPI_IOC_MESSAGE");
    }
}

static void nrf_read_rx_payload(uint8_t *buf, uint8_t len)
{
    uint8_t tx[1 + 32] = {0};
    uint8_t rx[1 + 32] = {0};

    if (len > 32) len = 32;

    tx[0] = NRF_CMD_R_RX_PAYLOAD;
    memset(&tx[1], NRF_CMD_NOP, len);

    struct spi_ioc_transfer tr = {
        .tx_buf = (unsigned long)tx,
        .rx_buf = (unsigned long)rx,
        .len    = len + 1,
        .speed_hz = 1000000,
        .delay_usecs = 0,
        .bits_per_word = 8,
    };

    if (ioctl(spi_fd, SPI_IOC_MESSAGE(1), &tr) < 0){
        perror("SPI_IOC_MESSAGE");
        return;
    }

    memcpy(buf, &rx[1], len);
}

static void nrf_flush_rx(void)
{
    (void)spi_xfer_byte(NRF_CMD_FLUSH_RX);
}

static void nrf_clear_irq(void)
{
    nrf_write_reg(NRF_REG_STATUS, NRF_RX_DR | NRF_TX_DS | NRF_MAX_RT);
}
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

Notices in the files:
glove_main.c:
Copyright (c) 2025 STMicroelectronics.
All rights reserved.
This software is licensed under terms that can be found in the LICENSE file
